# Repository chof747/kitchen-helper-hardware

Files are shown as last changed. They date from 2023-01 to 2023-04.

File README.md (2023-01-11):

# kitchen-helper-hardware
Hardware specs, schematics and pcb design for the kitchen helper device

The KitchenHelper consists of the following features:

- ESP32-S3 MCU 
- TFT Display
- 2 push buttons and a rotary encoder
- 2 cinch slots for NTC temperature sensors
- Buzzer to play sounds
- An addressable led row to show status information and progressy
- Battery and power management 
- Programming Header

## Verification

1. [Done] Programming Header 
2. [Done] Display
3. [Done] Buzzer
4. [Done] Push Buttons

5. [Open] Power and Battery Management
   - protection ICs
   - Voltage regulation
   - charging with charger board

6. [Open] Rotary Encoder schematic 
   - pull-up circuit

7. [Open] Addressable Status Leds 
   - level shifting, 
   - voltage from Battery

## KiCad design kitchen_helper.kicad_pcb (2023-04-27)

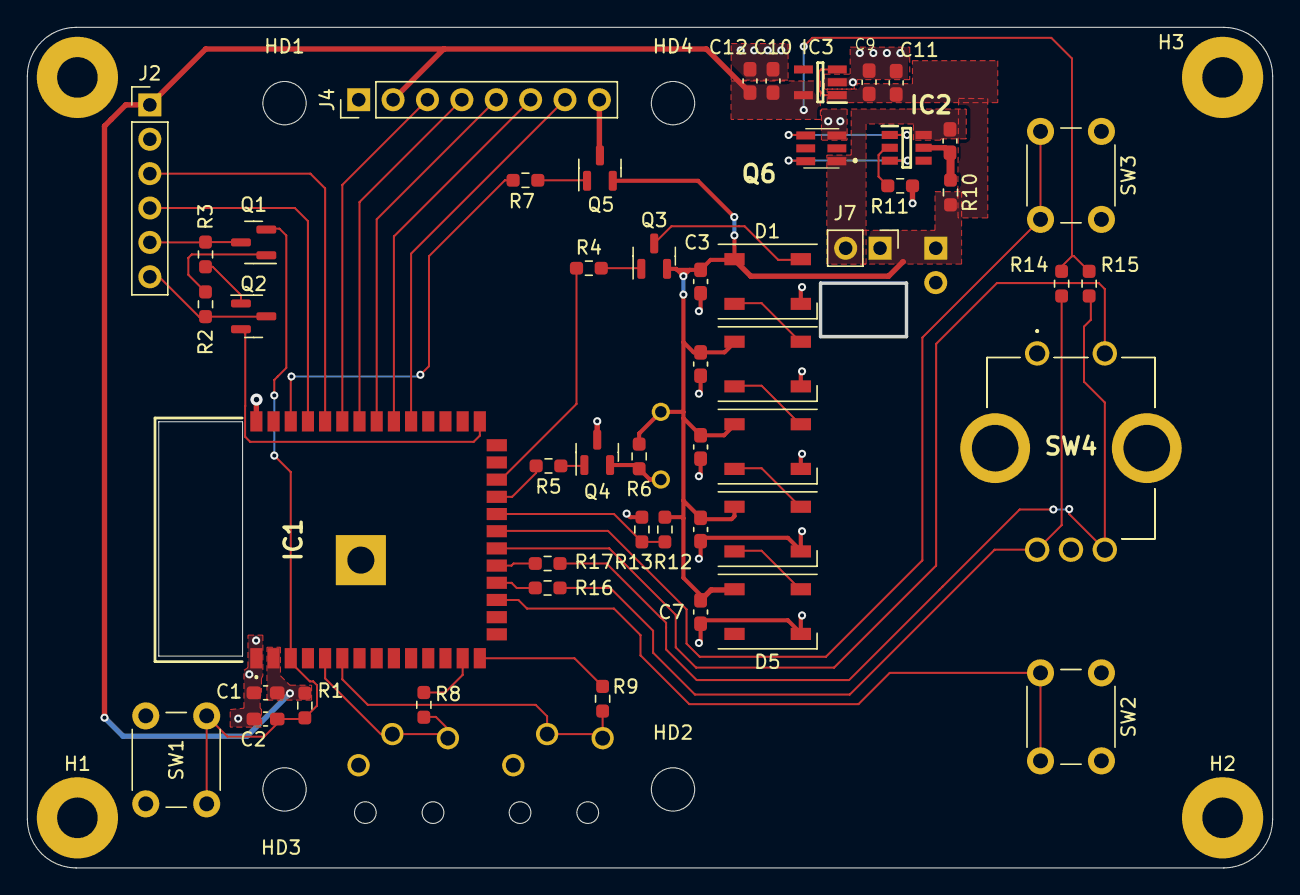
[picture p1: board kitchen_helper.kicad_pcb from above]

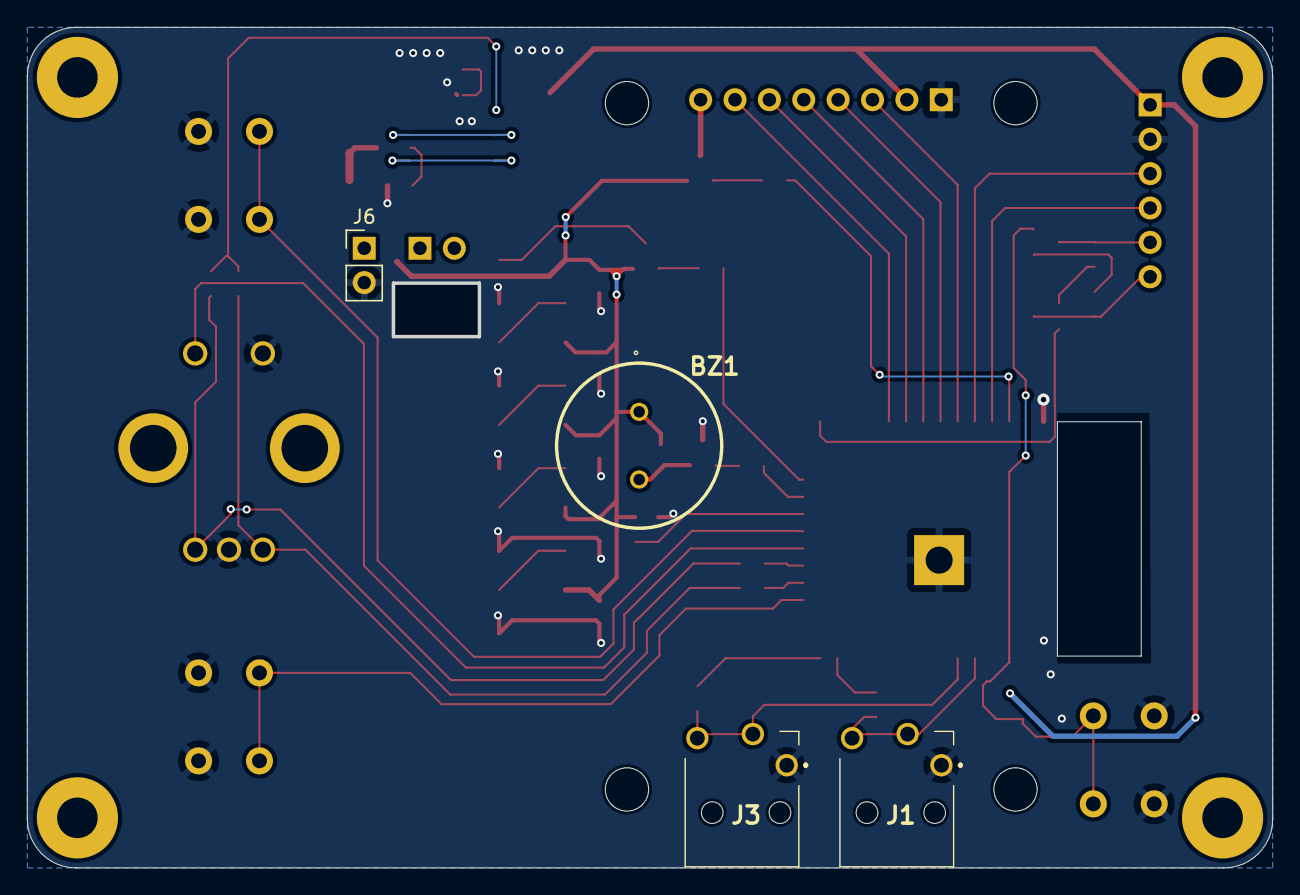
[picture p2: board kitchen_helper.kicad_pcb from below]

Board: 2 copper layers, 92.0 x 62.1 mm, 62 parts (4 on the bottom side), 46 nets.

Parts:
BZ1: Buzzer; PS1240P02BT
C1: 10uF; C_0603_1608Metric_Pad1.08x0.95mm_HandSolder
C2, C9, C10, C11, C12: 1uF; C_0603_1608Metric_Pad1.08x0.95mm_HandSolder
C3, C4, C5, C6, C7: 100nF; C_0603_1608Metric_Pad1.08x0.95mm_HandSolder
C8: 0.1uF; C_0603_1608Metric_Pad1.08x0.95mm_HandSolder
D1, D2, D3, D4, D5: WS2812B; LED_WS2812B_PLCC4_5.0x5.0mm_P3.2mm
H1, H2, H3, H4: MountingHole; MountingHole_3mm_Pad
HD1, HD2, HD3, HD4: MountingHole; MountingHole_3.2mm_M3
IC1: ESP32-S3-WROOM-1-N8R8; ESP32S3WROOM1N8R8
IC2: FS312F-G; SOT95P280X145-6N
IC3: VReg 3v3; SOT95P270X145-5N
J1: Temp 1; MJ2509N
J2: PROG_HDR; PinHeader_1x06_P2.54mm_Vertical
J3: Temp 2; MJ2509N
J4: DISP_HDR; PinHeader_1x08_P2.54mm_Vertical
J6: Charger; PinHeader_1x02_P2.54mm_Vertical
J7: Battery; PinHeader_1x02_P2.54mm_Vertical
Q1, Q2, Q3, Q4, Q5: SS8050-G; SOT-23
Q6: FS8205
R1, R12, R13, R14, R15: 22k; R_0603_1608Metric_Pad0.98x0.95mm_HandSolder
R2, R3: 10k; R_0603_1608Metric_Pad0.98x0.95mm_HandSolder
R4, R5, R6, R7, R16, R17: 1k; R_0603_1608Metric_Pad0.98x0.95mm_HandSolder
R8, R9: 100k; R_0603_1608Metric_Pad0.98x0.95mm_HandSolder
R10: 100; R_0603_1608Metric_Pad0.98x0.95mm_HandSolder
R11: 2k; R_0603_1608Metric_Pad0.98x0.95mm_HandSolder
SW1: SW_Reset; SW_PUSH_6mm
SW2: BTN_LEFT; SW_PUSH_6mm
SW3: BTN_RIGHT; SW_PUSH_6mm
SW4: RotaryEncoder_Switch; PEC12R3120FS0012

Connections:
GPIO0: IC1.27 (IO0), Q2.2 (C)
+3V3: C1.1, C10.1, C12.1, IC1.2 (3V3), IC3.5 (VOUT), J2.1, J4.2, R1.1, R14.2, R15.2
/BATT+: BZ1.1 (-), C3.1, C4.1, C5.1, C6.1, C7.1, C9.1, C11.1, D1.1 (VDD), D2.1 (VDD), D3.1 (VDD), D4.1 (VDD), D5.1 (VDD), IC3.1 (VIN), IC3.3 (CE), J6.1, J7.1, Q3.2 (C), Q5.2 (C), R6.2, R10.2, R12.1
/BTNLEFT_IO9: IC1.17 (IO9), SW2.2
/BTNRGHT_IO13: IC1.21 (IO13), SW3.2
/I40_DISPLAY_RESET: IC1.33 (IO40), J4.5
/IO02_DISPLAY_BKLT: IC1.38 (IO2), R7.2
/IO19_ADC_DRV0: IC1.13 (IO19), R8.1
/IO19_ADC_DRV1: IC1.14 (IO20), R9.1
/IO21_PWM_BUZZ: IC1.23 (IO21), R5.1
/IO38_DISPLAY_CS: IC1.31 (IO38), J4.7
/IO39_DISPLAY_RS: IC1.32 (IO39), J4.6
/IO41_DISPLAY_SDA: IC1.34 (IO41), J4.4
/IO42_DISPLAY_SCK: IC1.35 (IO42), J4.3
/IO47_LEDS_DAT: IC1.24 (IO47), R4.2
/Power Management/BATT-: C8.2, IC2.6 (GND), J7.2, Q6.1 (S1)
/Power Management/Bat-In: C8.1, IC2.5 (VCC), R10.1
/Power Management/CurrSense: IC2.2 (CS), R11.1
/Power Management/OvrChg: IC2.3 (OC), Q6.4 (G2)
/Power Management/OvrDisChg: IC2.1 (OD), Q6.6 (G1)
/REN_BTN_IO12: IC1.20 (IO12), SW4.2 (NO)
/REN_CLK_IO10: IC1.18 (IO10), R16.1
/REN_DAT_IO11: IC1.19 (IO11), R17.1
/TEMP1_AIO5: IC1.5 (IO5), J1.2, J1.3, R8.2
/TEMP2_AIO6: IC1.6 (IO6), J3.2, J3.3, R9.2
/VBat-Check: IC1.22 (IO14), R12.2, R13.1
DTR: J2.6, Q2.3 (E), R2.1
ESP32_RX: IC1.36 (RXD0), J2.3
ESP32_TX: IC1.37 (TXD0), J2.4
GND: C1.2, C2.2, C3.2, C4.2, C5.2, C6.2, C7.2, C9.2, C10.2, C11.2, C12.2, D1.3 (VSS), D2.3 (VSS), D3.3 (VSS), D4.3 (VSS), D5.3 (VSS), IC1.1 (GND_1), IC3.2 (VSS), J1.1, J2.2, J3.1, J4.1, J6.2, Q4.3 (E), Q6.3 (S2), R11.2, R13.2, SW1.1, SW2.1, SW3.1, SW4.1 (COM), SW4.C1 (COMMON)
unnamed: BZ1.2 (+), Q4.2 (C), R6.1
unnamed: D1.2 (DOUT), D2.4 (DIN)
unnamed: D1.4 (DIN), Q3.3 (E)
unnamed: D2.2 (DOUT), D3.4 (DIN)
unnamed: D3.2 (DOUT), D4.4 (DIN)
unnamed: D4.2 (DOUT), D5.4 (DIN)
unnamed: J4.8, Q5.3 (E)
unnamed: Q1.1 (B), R2.2
unnamed: Q2.1 (B), R3.2
unnamed: Q3.1 (B), R4.1
unnamed: Q4.1 (B), R5.2
unnamed: Q5.1 (B), R7.1
unnamed: R14.1, R16.2, SW4.A1 (CHANNEL_A)
unnamed: R15.1, R17.2, SW4.B1 (CHANNEL_B)
RTS: J2.5, Q1.3 (E), R3.1
~RESET: C2.1, IC1.3 (EN), Q1.2 (C), R1.2, SW1.2

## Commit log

2022-10-31 Initial version of kitchen helper hardware
    [kitchen_helper.kicad_pcb, kitchen_helper.kicad_sch, kitchen_helper.sch]
2022-11-29 Modifications for ADC ports
    - Changed voltage divider resistor to 100k
    - Changed the voltage supply for the ADC pins from 3v3 to a GPIO Pin to turn them on only as needeed.
    - Deleted some old files
    [kitchen_helper.kicad_pcb, kitchen_helper.kicad_sch, kitchen_helper.sch]
2023-01-13 Corrected issues found during schematic verification
    - splitted driving lines for both temperature sensors to prevent nfluencing through parallel resistance
    - swaped the two directions of the rotary encoder
    - Powering the TFT backlight from BATT+ as the voltage drop at the resistor is too much for 3v3
    - Added resistor network to directly pull rotary encorder to 3v3
    [kitchenHelper_peripherals.kicad_sch, kitchenHelper_pwr.kicad_sch, kitchen_helper.kicad_pcb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]
2023-01-13 Late save of schema file^:
    [kitchen_helper.kicad_sch]
2023-04-27 Migrated project to KiCad7
    [kitchenHelper_peripherals.kicad_sch, kitchenHelper_pwr.kicad_sch, kitchen_helper.kicad_pcb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]
